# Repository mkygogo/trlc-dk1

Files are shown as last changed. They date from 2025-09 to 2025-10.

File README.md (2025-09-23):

<p align="center">
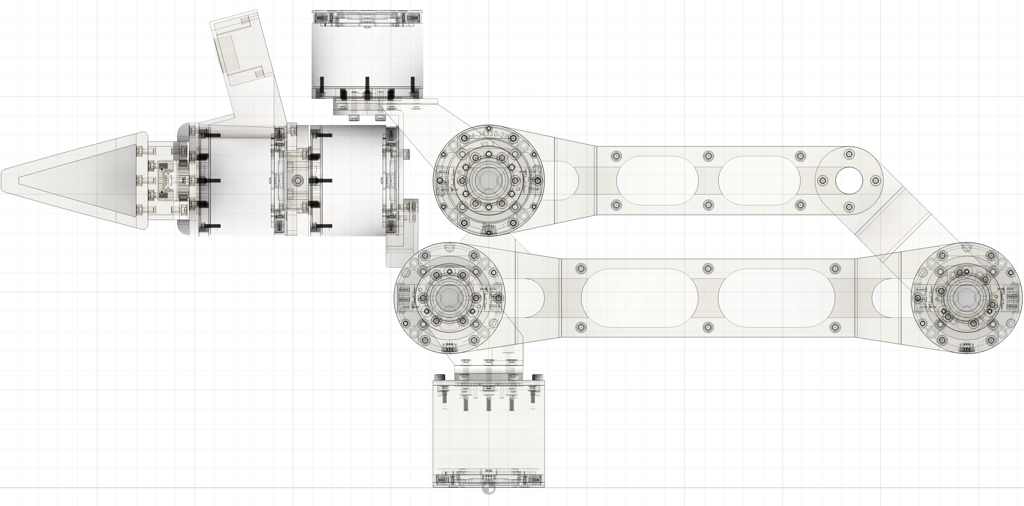
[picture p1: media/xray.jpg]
    
</p>
<p align="center">
    <a href="https://docs.robot-learning.co/">
        </a>
    <a href="https://discord.gg/PTZ3CN5WkJ">
        </a>
    <a href="https://x.com/JannikGrothusen">
        </a>
    <a href="https://www.robot-learning.co/">
        </a>
</p>

<h1 align="center">An Open Source Dev Kit for AI-native Robotics</h1>
<p align="center">by The Robot Learning Company</p>

## Demo

<p align="center">
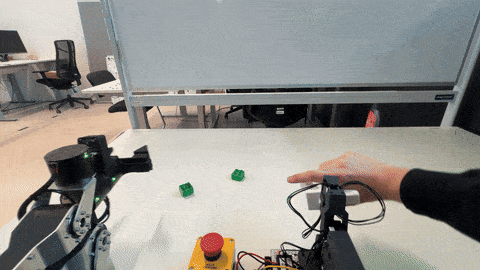
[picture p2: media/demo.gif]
    
</p>

## CAD

<table align="center">
<tr>
<td width="50%">
<a href="https://a360.co/48vL3j3" target="_blank">
TRLC-DK1 Follower CAD (Fusion)<br>
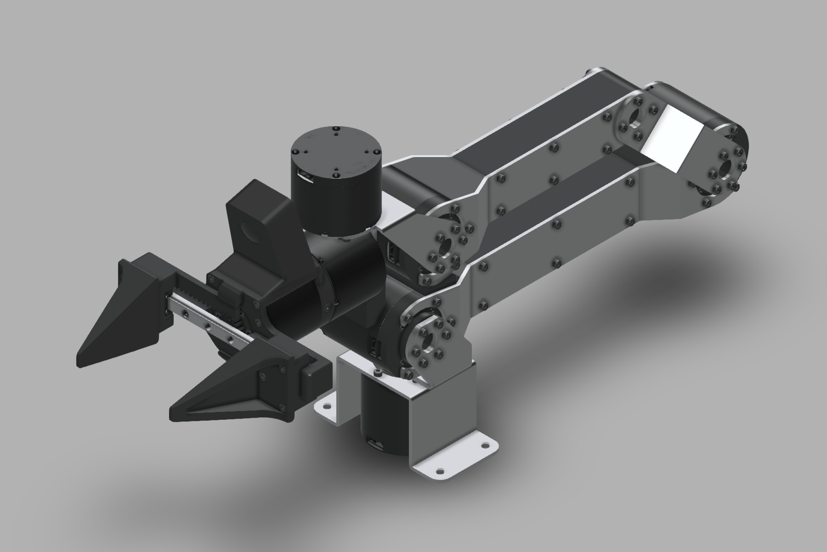
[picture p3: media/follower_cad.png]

</a>
</td>
<td width="50%">
<a href="https://a360.co/4nmVNVC" target="_blank">
TRLC-DK1 Leader CAD (Fusion)<br>
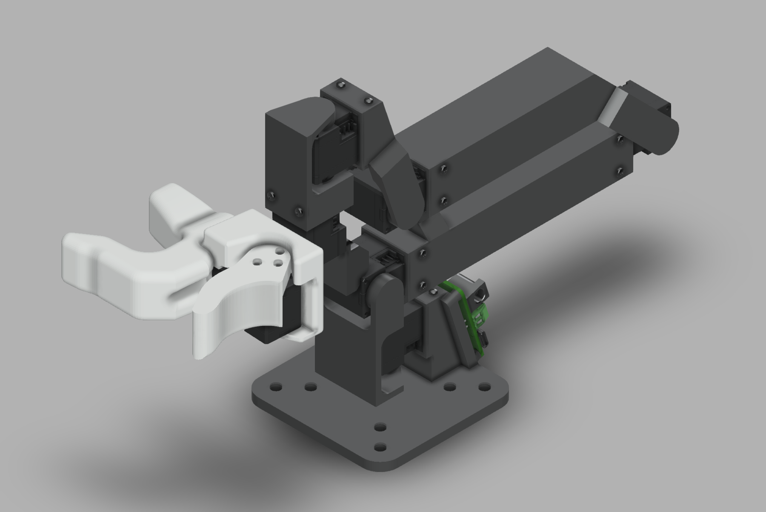
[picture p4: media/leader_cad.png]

</a>
</td>
</tr>
</table>
Copyright 2025 The Robot Learning Company UG (haftungsbeschränkt). All rights reserved.

## Installation

```
conda create -n dk1 python=3.10
conda activate dk1
pip install -e .
```

(This should also install [TRLC's fork of LeRobot](https://github.com/robot-learning-co/lerobot) and use branch `trlc-dk1`)

## Examples

Use [LeRobot's CLI](https://huggingface.co/docs/lerobot/il_robots) to identify your teleop and robot ports:

```
lerobot-find-port
```

<details>
<summary>Teleoperation
</summary>

```bash
lerobot-teleoperate \
    --robot.type=dk1_follower \
    --robot.port=/dev/tty.usbmodem00000000050C1 \
    --robot.joint_velocity_scaling=0.5 \
    --robot.cameras="{ 
        context: {type: opencv, index_or_path: 0, width: 1280, height: 720, fps: 30}, 
        wrist: {type: opencv, index_or_path: 1, width: 1280, height: 720, fps: 30}
      }" \
    --teleop.type=dk1_leader \
    --teleop.port=/dev/tty.usbmodem58FA0824311 \
    --display_data=true
```
</details>

<details>
<summary>Recording
</summary>

```bash
lerobot-record \
    --robot.type=dk1_follower \
    --robot.port=/dev/tty.usbmodem00000000050C1 \
    --robot.joint_velocity_scaling=1.0 \
    --robot.cameras="{ 
        context: {type: opencv, index_or_path: 0, width: 640, height: 360, fps: 30}, 
        wrist: {type: opencv, index_or_path: 1, width: 640, height: 360, fps: 30}
      }" \
    --teleop.type=dk1_leader \
    --teleop.port=/dev/tty.usbmodem58FA0824311 \
    --display_data=true \
    --dataset.repo_id=$USER/my_dataset \
    --dataset.push_to_hub=false \
    --dataset.num_episodes=50 \
    --dataset.episode_time_s=30 \
    --dataset.reset_time_s=15 \
    --dataset.single_task="My task description."
```
```bash
    --resume=true
```
</details>

<details>
<summary>Inference
</summary>

```bash
lerobot-record  \
  --robot.type=dk1_follower \
  --robot.port=/dev/tty.usbmodem00000000050C1 \
  --robot.joint_velocity_scaling=0.5 \
  --robot.cameras="{ 
      context: {type: opencv, index_or_path: 0, width: 640, height: 360, fps: 30}, 
      wrist: {type: opencv, index_or_path: 1, width: 640, height: 360, fps: 30}
    }"
  --display_data=true \
  --dataset.repo_id=$USER/eval_my_model \
  --dataset.single_task="My task description." \
  --dataset.push_to_hub=false \
  --policy.path=outputs/my_model/checkpoints/last/pretrained_model
```
</details>

## Acknowledgements

- [GELLO](https://wuphilipp.github.io/gello_site/) by Philipp Wu et al.
- [Low-Cost Robot Arm](https://github.com/AlexanderKoch-Koch/low_cost_robot) by Alexander Koch
- [LeRobot](https://github.com/huggingface/lerobot) by HuggingFace, Inc.
- [SO-100](https://github.com/TheRobotStudio/SO-ARM100) by TheRobotStudio
- [OpenArm](https://openarm.dev/) by Enactic, Inc.

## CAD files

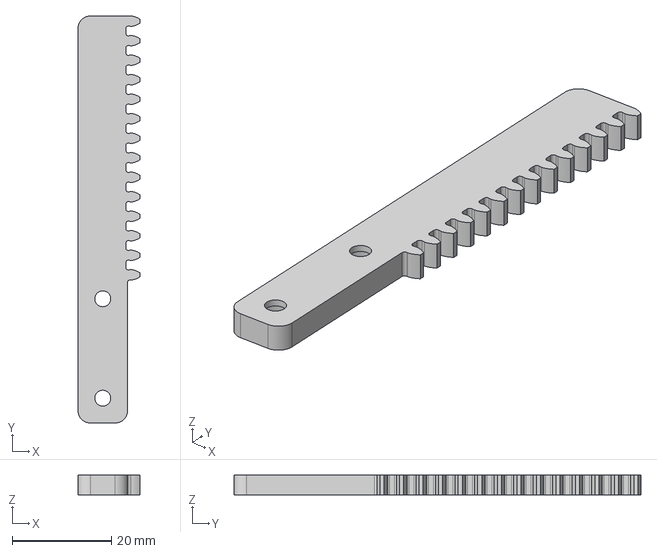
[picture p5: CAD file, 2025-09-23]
hardware/follower_parts/gripper/gear-rack_v0.1.0.step
12.5 x 81.9 x 4.00 mm

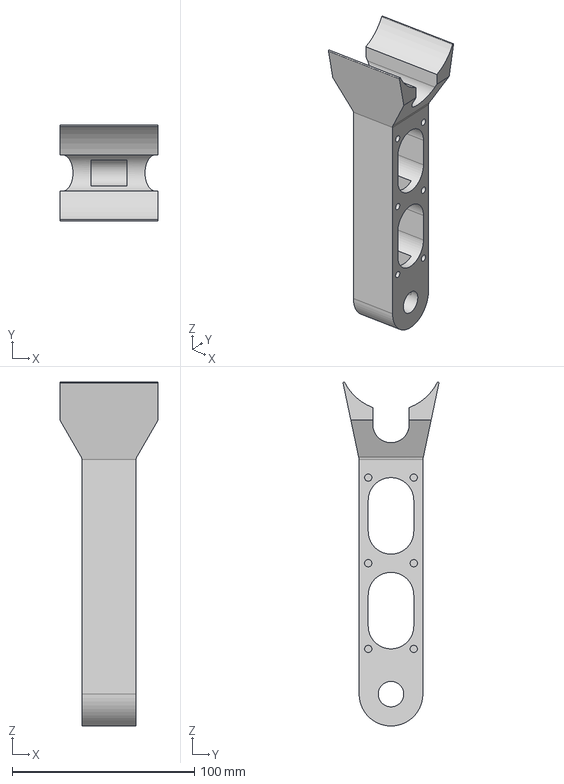
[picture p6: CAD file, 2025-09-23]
hardware/follower_parts/link3-4-frame_v0.1.0.step
54.0 x 52.7 x 188.8 mm

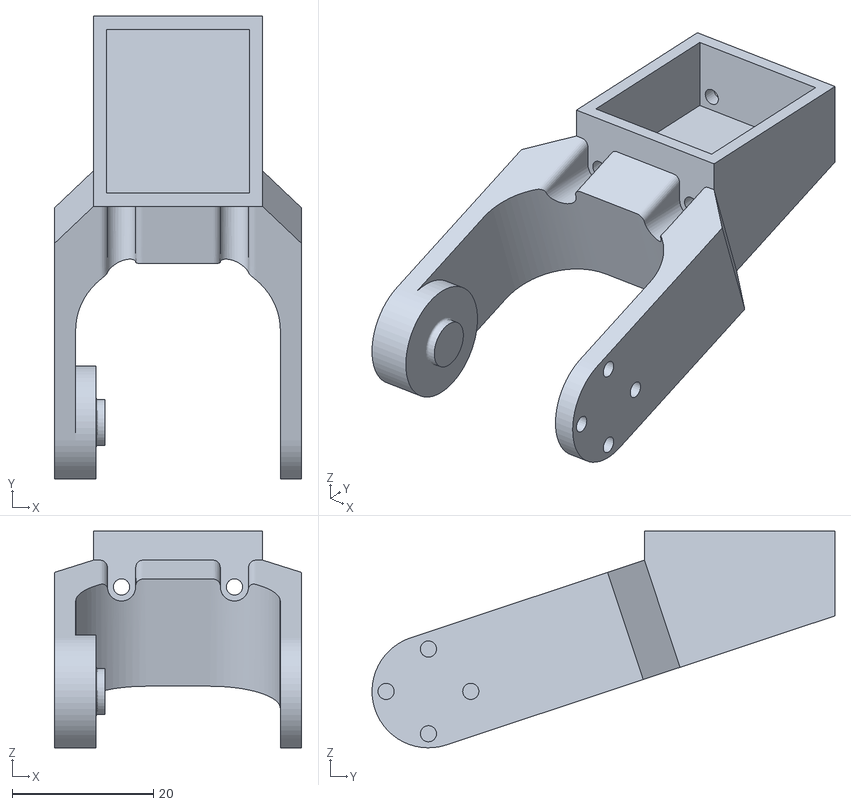
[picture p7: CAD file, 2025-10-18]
hardware/leader_parts/link4-5-flipped_v0.1.0.stl
35.0 x 65.6 x 30.7

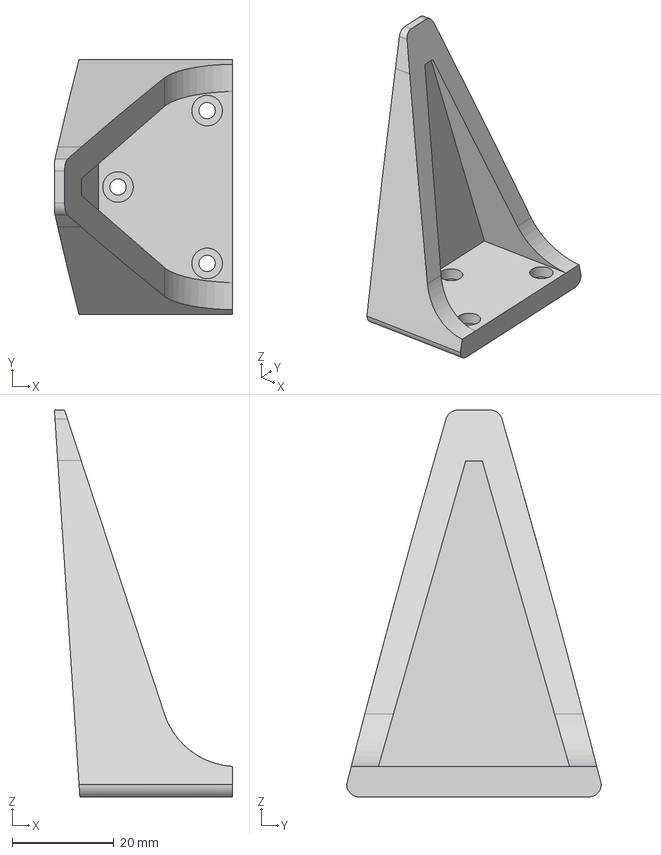
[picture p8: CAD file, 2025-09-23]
hardware/follower_parts/gripper/finger_v0.1.0.step
35.0 x 50.0 x 76.0 mm

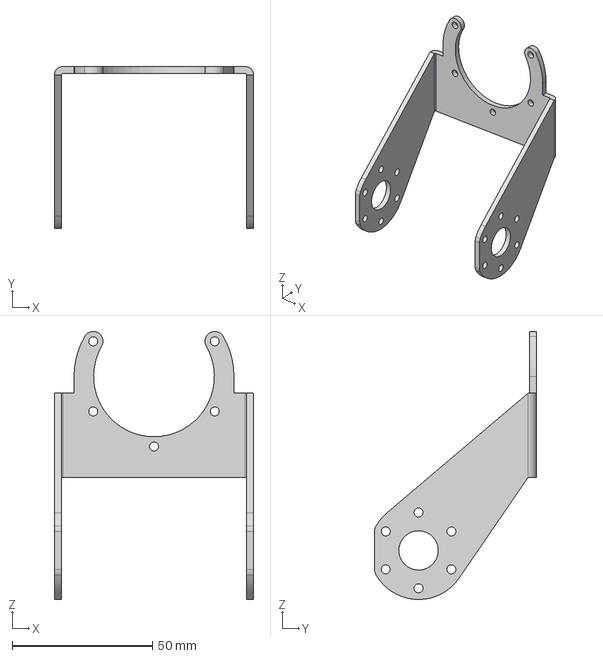
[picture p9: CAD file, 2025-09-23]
hardware/follower_parts/link4-5_v0.1.0.step
71.0 x 57.7 x 95.5 mm

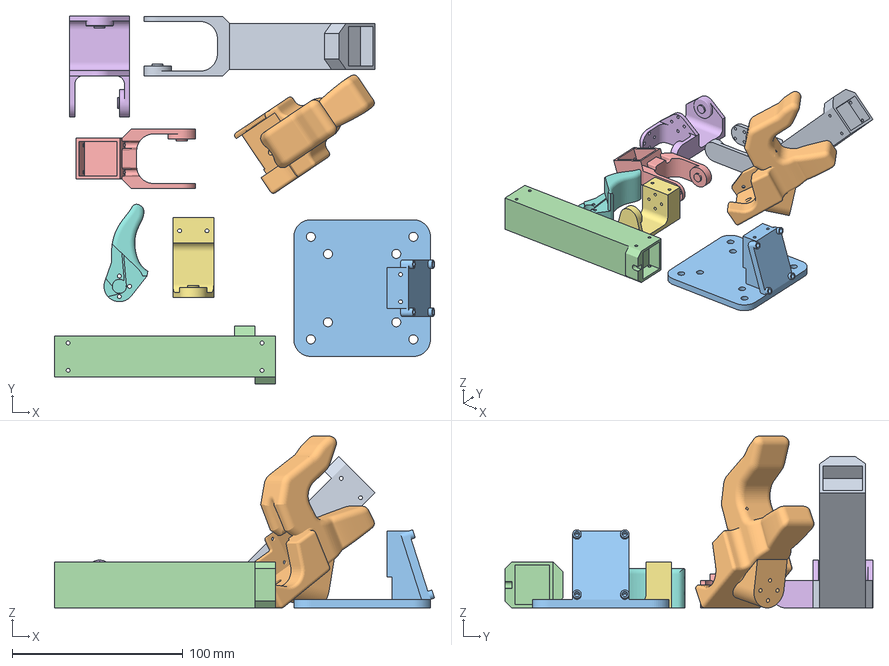
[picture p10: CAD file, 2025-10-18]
hardware/leader_parts/leader.3mf
222.4 x 215.4 x 100.6 mm
link3-4_v0.1.0.stl
gello_handle_45deg.stl
link0-1_v0.1.0.stl
link2-3_v0.1.0.stl
link4-5_v0.1.0.stl
link1-2_v0.1.0.stl
link5-6-1_v0.1.0.stl
gello_trigger.stl

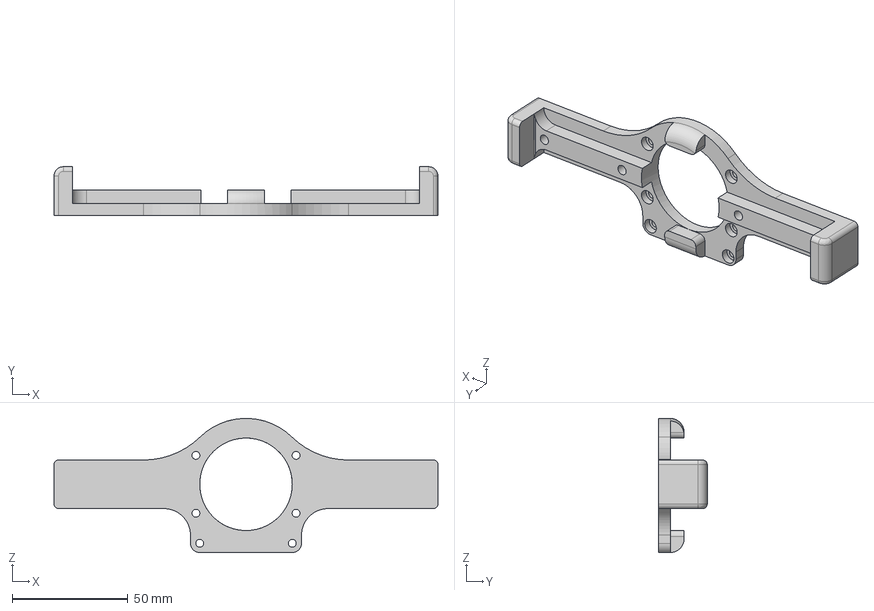
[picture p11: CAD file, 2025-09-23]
hardware/follower_parts/gripper/frame_v0.1.0.step
166.0 x 21.0 x 58.0 mm

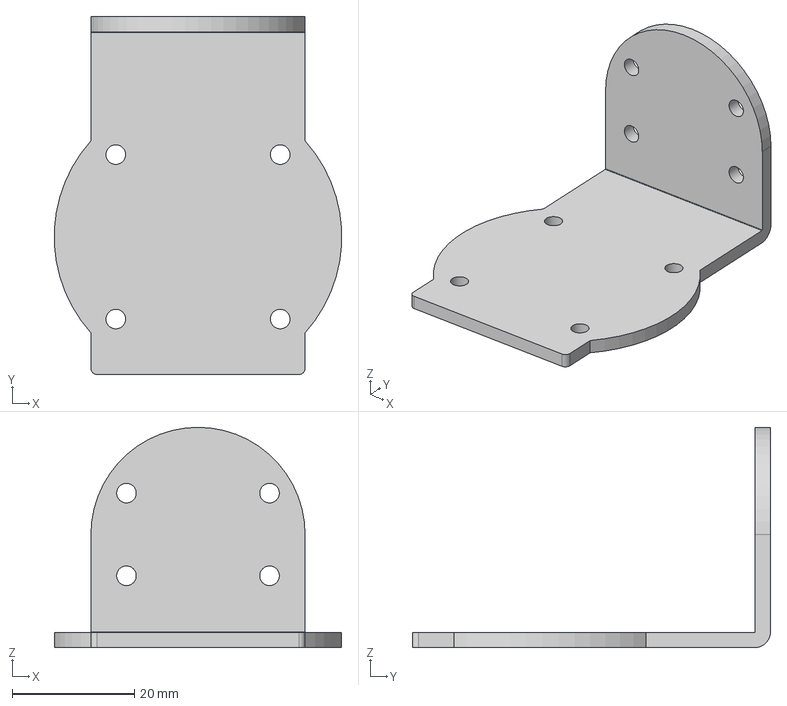
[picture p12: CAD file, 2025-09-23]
hardware/follower_parts/link5-6_v0.1.0.step
46.9 x 58.5 x 36.0 mm

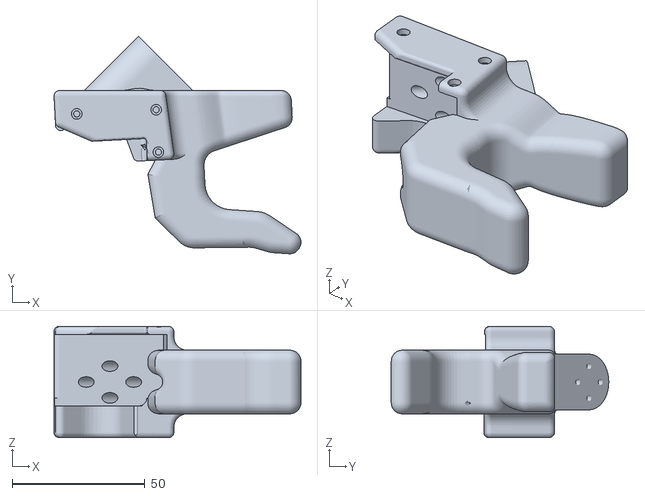
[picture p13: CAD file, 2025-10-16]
hardware/leader_parts/gello_handle_45deg.stl
93.2 x 82.1 x 42.0

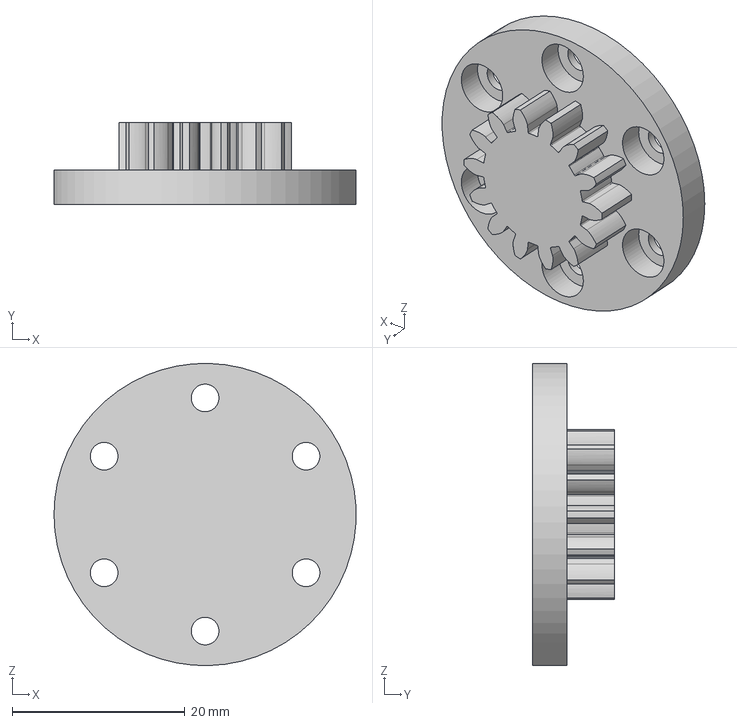
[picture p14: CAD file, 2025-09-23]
hardware/follower_parts/gripper/gear-shaft_v0.1.0.step
35.0 x 9.50 x 35.0 mm

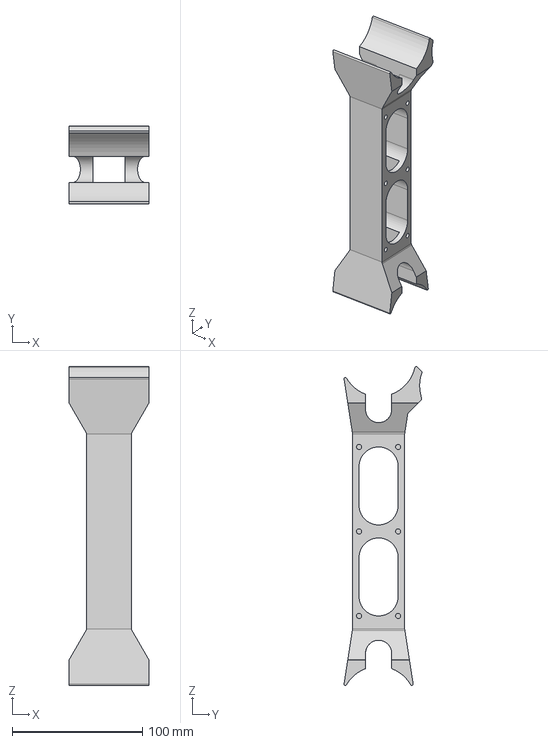
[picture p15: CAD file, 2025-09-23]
hardware/follower_parts/link2-3-frame_v0.1.0.step
61.2 x 59.8 x 244.8 mm

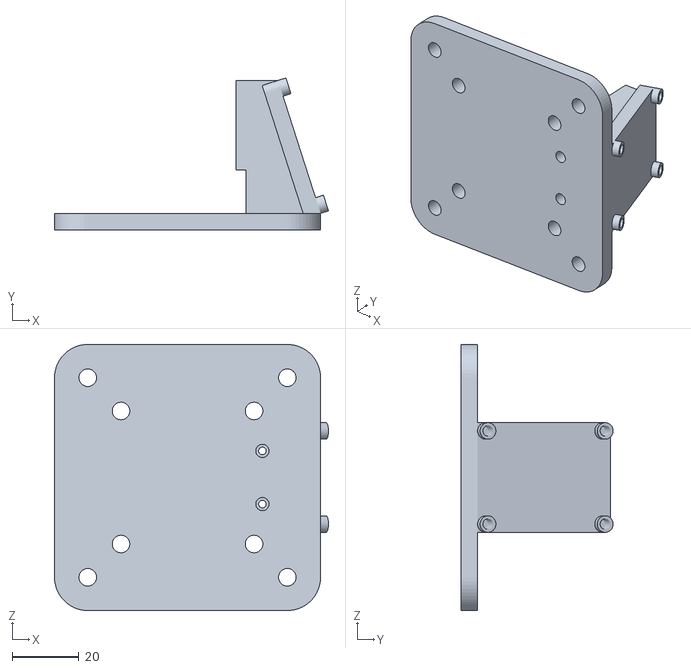
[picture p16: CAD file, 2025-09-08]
hardware/leader_parts/link0-1_v0.1.0.stl
82.4 x 45.7 x 80.0

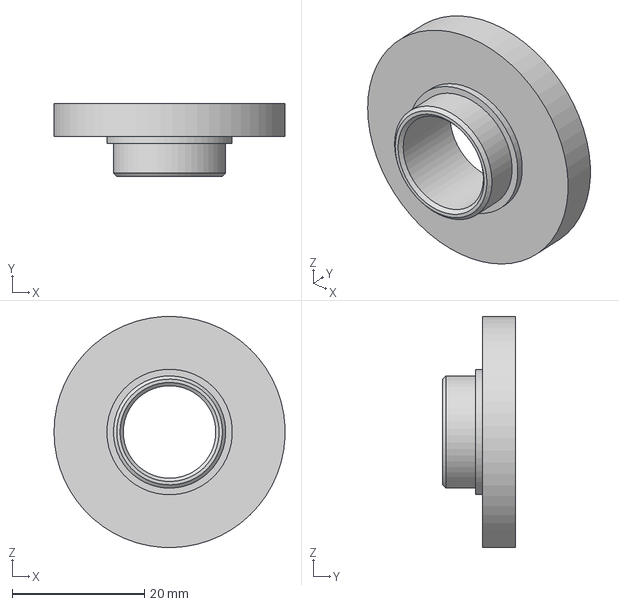
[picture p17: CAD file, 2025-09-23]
hardware/follower_parts/dm-idler_v0.1.0.step
35.0 x 11.0 x 35.0 mm

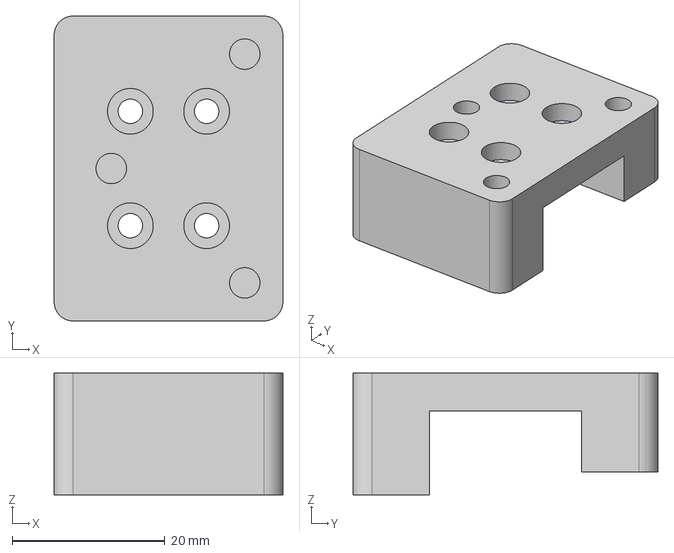
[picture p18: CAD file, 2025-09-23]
hardware/follower_parts/gripper/block-adapter_v0.1.0.step
30.0 x 40.0 x 16.0 mm

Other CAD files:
hardware/leader_parts/link5-6-1_v0.1.0.stl
hardware/follower_parts/gripper/uvc-camera-mount_v0.1.0.step
hardware/follower_parts/link3-4-1_v0.1.0.step
hardware/leader_parts/link3-4_v0.1.0.stl
hardware/follower_parts/dm-adapter_v0.1.0.step
hardware/follower_parts/dm-adapter_v0.1.0.stl
hardware/follower_parts/dm-idler_v0.1.0.stl
hardware/follower_parts/dm-shaft-extension_v0.1.0.step
hardware/follower_parts/dm-shaft-extension_v0.1.0.stl
hardware/follower_parts/gripper/block-adapter_v0.1.0.stl
hardware/follower_parts/gripper/d405-camera-mount_v0.1.0.step
hardware/follower_parts/gripper/d405-camera-mount_v0.1.0.stl
hardware/follower_parts/gripper/finger_v0.1.0.stl
hardware/follower_parts/gripper/frame_v0.1.0.stl
hardware/follower_parts/gripper/gear-rack_v0.1.0.stl
hardware/follower_parts/gripper/gear-shaft_v0.1.0.stl
hardware/follower_parts/gripper/link6-7-1_v0.1.0.step
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

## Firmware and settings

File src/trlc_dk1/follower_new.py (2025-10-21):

#   Copyright 2025 The Robot Learning Company UG (haftungsbeschränkt). All rights reserved.
#
#   Licensed under the Apache License, Version 2.0 (the "License");
#   you may not use this file except in compliance with the License.
#   You may obtain a copy of the License at
#
#       http://www.apache.org/licenses/LICENSE-2.0
#
#   Unless required by applicable law or agreed to in writing, software
#   distributed under the License is distributed on an "AS IS" BASIS,
#   WITHOUT WARRANTIES OR CONDITIONS OF ANY KIND, either express or implied.
#   See the License for the specific language governing permissions and
#   limitations under the License.

from dataclasses import dataclass, field
from functools import cached_property
import serial
import time
import logging
from typing import Any

from lerobot.cameras import CameraConfig
from lerobot.cameras.utils import make_cameras_from_configs
from lerobot.robots import Robot, RobotConfig
from lerobot.robots.utils import ensure_safe_goal_position
from lerobot.utils.errors import DeviceAlreadyConnectedError, DeviceNotConnectedError

#from trlc_dk1.motors.DM_Control_Python.DM_CAN import *
from motors.DM_Control_Python.DM_CAN import *

logger = logging.getLogger(__name__)


def map_range(x: float, in_min: float, in_max: float, out_min: float, out_max: float) -> float:
    return (x - in_min) * (out_max - out_min) / (in_max - in_min) + out_min


@RobotConfig.register_subclass("dk1_follower")
@dataclass
class DK1FollowerConfig(RobotConfig):
    port: str
    disable_torque_on_disconnect: bool = False
    joint_velocity_scaling: float = 0.2
    max_gripper_torque: float = 1.0 # Nm (/0.00875m spur gear radius = 114N gripper force)
    cameras: dict[str, CameraConfig] = field(default_factory=dict)


class DK1Follower(Robot):
    """
    TRLC-DK1 Follower Arm designed by The Robot Learning Company.
    """

    config_class = DK1FollowerConfig
    name = "dk1_follower"

    def __init__(self, config: DK1FollowerConfig):
        super().__init__(config)
        
        # Constants for EMIT control
        self.DM4310_TORQUE_CONSTANT = 0.945  # Nm/A
        self.EMIT_VELOCITY_SCALE = 100  # rad/s
        self.EMIT_CURRENT_SCALE = 1000  # A
        
        self.DM4310_SPEED = 200/60*2*np.pi   # rad/s (200  rpm | 20.94 rad/s)
        self.DM4340_SPEED = 52.5/60*2*np.pi  # rad/s (52.5 rpm | 5.49  rad/s)

        self.config = config
        self.motors = {
            "joint_1": Motor(DM_Motor_Type.DM4340, 0x01, 0x11),
            "joint_2": Motor(DM_Motor_Type.DM4340, 0x02, 0x12),
            "joint_3": Motor(DM_Motor_Type.DM4340, 0x03, 0x13),
            "joint_4": Motor(DM_Motor_Type.DM4310, 0x04, 0x14),
            "joint_5": Motor(DM_Motor_Type.DM4310, 0x05, 0x15),
            "joint_6": Motor(DM_Motor_Type.DM4310, 0x06, 0x16),
            "gripper": Motor(DM_Motor_Type.DM4310, 0x07, 0x17),
        }
        self.control = None
        self.serial_device = None
        self.bus_connected = False

        self.gripper_open_pos = 0.0
        self.gripper_closed_pos = -4.7

        self.cameras = make_cameras_from_configs(config.cameras)

    @property
    def _motors_ft(self) -> dict[str, type]:
        return {f"{motor}.pos": float for motor in self.motors}

    @property
    def _cameras_ft(self) -> dict[str, tuple]:
        return {
            cam: (self.config.cameras[cam].height, self.config.cameras[cam].width, 3) for cam in self.cameras
        }

    @cached_property
    def observation_features(self) -> dict[str, type | tuple]:
        return {**self._motors_ft, **self._cameras_ft}

    @cached_property
    def action_features(self) -> dict[str, type]:
        return self._motors_ft

    @property
    def is_connected(self) -> bool:
        return self.bus_connected and all(cam.is_connected for cam in self.cameras.values())

    def connect(self) -> None:
        if self.is_connected:
            raise DeviceAlreadyConnectedError(f"{self} already connected")

        self.serial_device = serial.Serial(
            self.config.port, 921600, timeout=0.5)
        time.sleep(0.5)

        self.control = MotorControl(self.serial_device)
        self.bus_connected = True
        self.configure()

        for cam in self.cameras.values():
            cam.connect()

    @property
    def is_calibrated(self) -> bool:
        return True

    def calibrate(self) -> None:
        pass

    def configure(self) -> None:

        for key, motor in self.motors.items():
            self.control.addMotor(motor)

            for _ in range(3):
                self.control.refresh_motor_status(motor)
                time.sleep(0.01)

            if self.control.read_motor_param(motor, DM_variable.CTRL_MODE) is not None:
                print(f"{key} ({motor.MotorType.name}) is connected.")

                self.control.switchControlMode(motor, Control_Type.POS_VEL)
                self.control.enable(motor)
            else:
                raise Exception(
                    f"Unable to read from {key} ({motor.MotorType.name}).")

        for joint in ["joint_1", "joint_2", "joint_3"]:
            self.control.change_motor_param(self.motors[joint], DM_variable.ACC, 10.0)
            self.control.change_motor_param(self.motors[joint], DM_variable.DEC, -10.0)
            self.control.change_motor_param(self.motors[joint], DM_variable.KP_APR, 200)
            self.control.change_motor_param(self.motors[joint], DM_variable.KI_APR, 10)

        for joint in ["gripper"]:
            self.control.change_motor_param(
                self.motors[joint], DM_variable.KP_APR, 100)

        #set 1~6 motor to zero 
        logger.info("开始设置电机零位...")
        for joint in ["joint_1", "joint_2", "joint_3", "joint_4", "joint_5", "joint_6"]:
            try:
                logger.info(f"设置 {joint} 零位...")
                self.control.set_zero_position(self.motors[joint])
                time.sleep(0.1)
                
                # 验证零位设置
                self.control.refresh_motor_status(motor)
                new_pos = motor.getPosition()
                logger.info(f"  {joint}: 设零后位置 = {new_pos:.3f} rad")
                
            except Exception as e:
                logger.error(f"设置 {joint} 零位失败: {e}")

        #Open gripper and set zero position
        self.control.switchControlMode(
            self.motors["gripper"], Control_Type.VEL)
        self.control.control_Vel(self.motors["gripper"], 10.0)
        while True:
            self.control.refresh_motor_status(self.motors["gripper"])
            tau = self.motors["gripper"].getTorque()
            if tau > 0.6: #0.8
                self.control.control_Vel(self.motors["gripper"], 0.0)
                self.control.disable(self.motors["gripper"])
                self.control.set_zero_position(self.motors["gripper"])
                time.sleep(0.2)
                self.control.enable(self.motors["gripper"])
                break
            time.sleep(0.01)
        self.control.switchControlMode(
            self.motors["gripper"], Control_Type.Torque_Pos)

    def get_observation(self) -> dict[str, Any]:
        if not self.is_connected:
            raise DeviceNotConnectedError(f"{self} is not connected.")

        # Read arm position
        start = time.perf_counter()

        obs_dict = {}
        for key, motor in self.motors.items():
            self.control.refresh_motor_status(motor)
            if 0: 
                pass
            if key == "gripper":
                # Normalize gripper position between 1 (closed) and 0 (open)
                obs_dict[f"{key}.pos"] = map_range(
                    motor.getPosition(), self.gripper_open_pos, self.gripper_closed_pos, 0.0, 1.0)
            else:
                obs_dict[f"{key}.pos"] = motor.getPosition()

        dt_ms = (time.perf_counter() - start) * 1e3
        logger.debug(f"{self} read state: {dt_ms:.1f}ms")

        # Capture images from cameras
        for cam_key, cam in self.cameras.items():
            start = time.perf_counter()
            obs_dict[cam_key] = cam.async_read()
            dt_ms = (time.perf_counter() - start) * 1e3
            logger.debug(f"{self} read {cam_key}: {dt_ms:.1f}ms")

        return obs_dict

    def send_action(self, action: dict[str, Any]) -> dict[str, Any]:
        if not self.is_connected:
            raise DeviceNotConnectedError(f"{self} is not connected.")

        goal_pos = {key.removesuffix(
            ".pos"): val for key, val in action.items() if key.endswith(".pos")}

        # Send goal position to the arm
        for key, motor in self.motors.items():
            if 0:
                pass
            if key == "gripper":
                self.control.refresh_motor_status(motor)
                gripper_goal_pos_mapped = map_range(goal_pos[key], 0.0, 1.0, self.gripper_open_pos, self.gripper_closed_pos)
                self.control.control_pos_force(motor, gripper_goal_pos_mapped, self.DM4310_SPEED*self.EMIT_VELOCITY_SCALE,
                                               i_des=self.config.max_gripper_torque/self.DM4310_TORQUE_CONSTANT*self.EMIT_CURRENT_SCALE)
            else:
                self.control.control_Pos_Vel(
                    motor, goal_pos[key], self.config.joint_velocity_scaling*self.DM4340_SPEED)

        return {f"{motor}.pos": val for motor, val in goal_pos.items()}

    def disconnect(self):
        if not self.is_connected:
            raise DeviceNotConnectedError(f"{self} is not connected.")

        if self.config.disable_torque_on_disconnect:
            for motor in self.motors.values():
                self.control.disable(motor)
        else:
            self.control.serial_.close()
        self.bus_connected = False

        for cam in self.cameras.values():
            cam.disconnect()

        logger.info(f"{self} disconnected.")


if __name__ == "__main__":
    import time


    follower_config = DK1FollowerConfig(
        port="/dev/ttyACM0",
        joint_velocity_scaling=1.0,
    )

    follower = DK1Follower(follower_config)
    follower.connect()

    obs =  follower.get_observation()
    print("obs:")
    print(obs)

    def gen_action(seed):

        return {'joint_1.pos': 0.2*seed, 
                'joint_2.pos': 0.2*seed, 
                'joint_3.pos': 0.2*seed, 
                'joint_4.pos': 0.2*seed, 
                'joint_5.pos': 0.2*seed, 
                'joint_6.pos': 0.2*seed,
                'joint_7.pos': 0.2*seed}


    try:
        seed = 1
        while True:
            seed+=1
            action = gen_action(seed)
            #follower.send_action(action)    
            time.sleep(0.2)
    except KeyboardInterrupt:
        print("\nStopping teleop...")
        
        follower.disconnect()

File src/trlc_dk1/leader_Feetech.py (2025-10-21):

#   Copyright 2025 The Robot Learning Company UG (haftungsbeschränkt). All rights reserved.
#
#   Licensed under the Apache License, Version 2.0 (the "License");
#   you may not use this file except in compliance with the License.
#   You may obtain a copy of the License at
#
#       http://www.apache.org/licenses/LICENSE-2.0
#
#   Unless required by applicable law or agreed to in writing, software
#   distributed under the License is distributed on an "AS IS" BASIS,
#   WITHOUT WARRANTIES OR CONDITIONS OF ANY KIND, either express or implied.
#   See the License for the specific language governing permissions and
#   limitations under the License.

from dataclasses import dataclass
import logging
import time
import numpy as np

from lerobot.teleoperators.teleoperator import Teleoperator, TeleoperatorConfig
from lerobot.utils.errors import DeviceAlreadyConnectedError, DeviceNotConnectedError
from lerobot.motors import Motor, MotorNormMode
#from lerobot.motors.dynamixel import (
#    DynamixelMotorsBus,
#    OperatingMode,
#)
from lerobot.motors.feetech import (
    FeetechMotorsBus,
    OperatingMode,
)
    
    

logger = logging.getLogger(__name__)


@TeleoperatorConfig.register_subclass("dk1_leader")
@dataclass
class DK1LeaderConfig(TeleoperatorConfig):
    port: str
    gripper_open_pos: int = 2280
    gripper_closed_pos: int = 1670
    
    
class DK1Leader(Teleoperator):
    config_class = DK1LeaderConfig
    name = "dk1_leader"

    def __init__(self, config: DK1LeaderConfig):
        super().__init__(config)
        self.config = config
        self.bus = FeetechMotorsBus(
            port=self.config.port,
            motors={
                "joint_1": Motor(1, "sts3215", MotorNormMode.DEGREES),
                "joint_2": Motor(2, "sts3215", MotorNormMode.DEGREES),
                "joint_3": Motor(3, "sts3215", MotorNormMode.DEGREES),
                "joint_4": Motor(4, "sts3215", MotorNormMode.DEGREES),
                "joint_5": Motor(5, "sts3215", MotorNormMode.DEGREES),
                "joint_6": Motor(6, "sts3215", MotorNormMode.DEGREES),
                #"gripper": Motor(7, "xl330-m077", MotorNormMode.DEGREES),
            },
        )

    @property
    def action_features(self) -> dict[str, type]:
        return {f"{motor}.pos": float for motor in self.bus.motors}

    @property
    def feedback_features(self) -> dict[str, type]:
        return {}

    @property
    def is_connected(self) -> bool:
        return self.bus.is_connected

    def connect(self, calibrate: bool = False) -> None:
        if self.is_connected:
            raise DeviceAlreadyConnectedError(f"{self} already connected")

        self.bus.connect()
        self.configure()
        
        logger.info(f"{self} connected.")

    @property
    def is_calibrated(self) -> bool:
        return True

    def calibrate(self) -> None:
        pass

    def configure(self) -> None:
        self.bus.disable_torque()
        self.bus.configure_motors()
        
        # Enable torque and set to position to open
        #self.bus.write("Torque_Enable", "gripper", 0, normalize=False)
        #self.bus.write("Operating_Mode", "gripper", OperatingMode.CURRENT_POSITION.value, normalize=False)
        #self.bus.write("Current_Limit", "gripper", 100, normalize=False)
        #self.bus.write("Torque_Enable", "gripper", 1, normalize=False)
        #self.bus.write("Goal_Position", "gripper", self.config.gripper_open_pos, normalize=False)
        
    def setup_motors(self) -> None:
        for motor in self.bus.motors:
            input(f"Connect the controller board to the '{motor}' motor only and press enter.")
            self.bus.setup_motor(motor)
            print(f"'{motor}' motor id set to {self.bus.motors[motor].id}")

    def get_action(self) -> dict[str, float]:
        if not self.is_connected:
            raise DeviceNotConnectedError(f"{self} is not connected.")

        start = time.perf_counter()
        
        action = self.bus.sync_read(normalize=False, data_name="Present_Position")
        action = {f"{motor}.pos": (val/4096*2*np.pi-np.pi) if motor != "gripper" else val for motor, val in action.items()}
        
        # # Normalize gripper position between 1 (closed) and 0 (open)
        gripper_range = self.config.gripper_open_pos - self.config.gripper_closed_pos
        #action["gripper.pos"] = 1 - (action["gripper.pos"] - self.config.gripper_closed_pos) / gripper_range
        
        dt_ms = (time.perf_counter() - start) * 1e3
        logger.debug(f"{self} read action: {dt_ms:.1f}ms")
        return action

    def send_feedback(self, feedback: dict[str, float]) -> None:
        # TODO(rcadene, aliberts): Implement force feedback
        raise NotImplementedError

    def disconnect(self) -> None:
        if not self.is_connected:
            raise DeviceNotConnectedError(f"{self} is not connected.")

        self.bus.disconnect()
        logger.info(f"{self} disconnected.")



if __name__ == "__main__" :
    leader_config = DK1LeaderConfig(
        port="/dev/ttyACM0"
    )

    leader = DK1Leader(leader_config)
    leader.connect()

    freq = 1 # Hz 200

    try:
        while True:
            action = leader.get_action()
            print(action)
            time.sleep(1/freq)
    except KeyboardInterrupt:
        print("\nStopping teleop...")
        leader.disconnect()
        

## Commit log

2025-08-01 Add initial testing code for Damiao motors
2025-08-01 Fix incorrect current translation factor
2025-08-01 Add motor and gripper test scripts
2025-08-28 Hardcode gripper calibrations
2025-09-06 Refactor default control values and gripper control
2025-09-06 Add x-ray image of follower arm
2025-09-08 Add script to read motor parameters
2025-09-08 Update motor speed constants
2025-09-08 Add helper script for leader joint offsets
2025-09-08 Include leader STLs
    [gello_handle.STL, gello_trigger.STL, link0-1 v7.stl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]
2025-09-18 Remove gripper torque limit warning
2025-09-18 Fix gripper range mapping to be consistent
    [follower.py]
2025-09-20 Rename STLs and folder
    [gello_handle.STL, gello_trigger.STL, link0-1_v0.1.0.stl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]
2025-09-23 Add v0.1.0 follower parts
    [block-adapter_v0.1.0.step, block-adapter_v0.1.0.stl, d405-camera-mount_v0.1.0.step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]
2025-09-23 Add CAD links and images
2025-09-23 Fix CAD image arrangement
2025-09-23 Add copyright notice to CAD files section
2025-09-24 Update leader CAD preview image
2025-10-16 Add modified GELLO handle
    [gello_handle_45deg.stl]
2025-10-18 Add Bambu Lab 3MF project file
    [leader.3mf]
2025-10-18 Add flipped link4-5
    [link4-5-flipped_v0.1.0.stl]
2025-10-20 Add script to calibrate follower arm
2025-10-20 Add script to read follower joint positions
